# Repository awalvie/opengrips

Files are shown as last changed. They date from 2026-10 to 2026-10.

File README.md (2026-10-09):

<div align="center">
  opengrips icon
  <h1>opengrips</h1>
  <p>A lift block for finger training that you can print yourself, with grips you swap by hand. Think of a portable hangboard.</p>
  <p>
    <a href="https://awalvie.github.io/opengrips/">Configurator</a> ·
    <a href="PRINTING.md">Printing guide</a> ·
    <a href="TODO.md">To do</a> ·
    <a href="https://github.com/awalvie/opengrips/issues">Issues</a>
  </p>
</div>

opengrips is a lift block for finger training. One housing hangs off a carabiner, and the grips slide into it and click in place: edges, pockets and rollers.

You can build your own at [awalvie.github.io/opengrips](https://awalvie.github.io/opengrips/). Pick your grips, change the depth and the shape, and download the files. It all runs in your browser, and the page link keeps your kit, so you can bookmark it or share it.

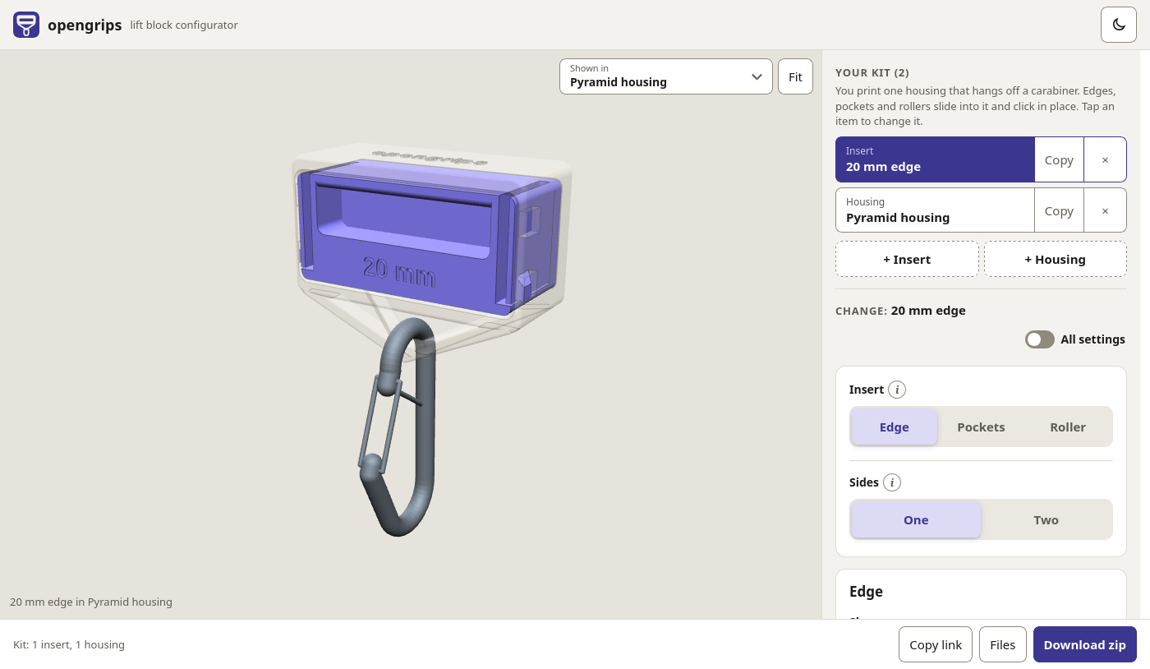
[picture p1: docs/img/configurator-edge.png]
The configurator with a 20 mm edge in the pyramid housing


This is a prototype, and I haven't load-tested it yet. Print and use it at your own risk, check it before every session, and stop using any part that cracks.

## What you can make

- Edges from 6 to 35 mm deep: flat, ergo, incut up to 20°, or slopers down to 45°.
- Two-sided inserts: any edge or pocket insert can get a second grip on its underside. Each grip is a flat or ergo edge or a row of pockets, 6 to 30 mm deep. Turn the insert over to switch.
- Pockets: mono, two-finger, three-finger, or up to three side by side.
- Rollers: unlevel or straight.
- Two anchors under the housing: a pyramid of four bars, or a keel plate with a hole.

Every anchor holds the carabiner right under the grip, so the edge should stay level when you pull. I haven't measured that yet.

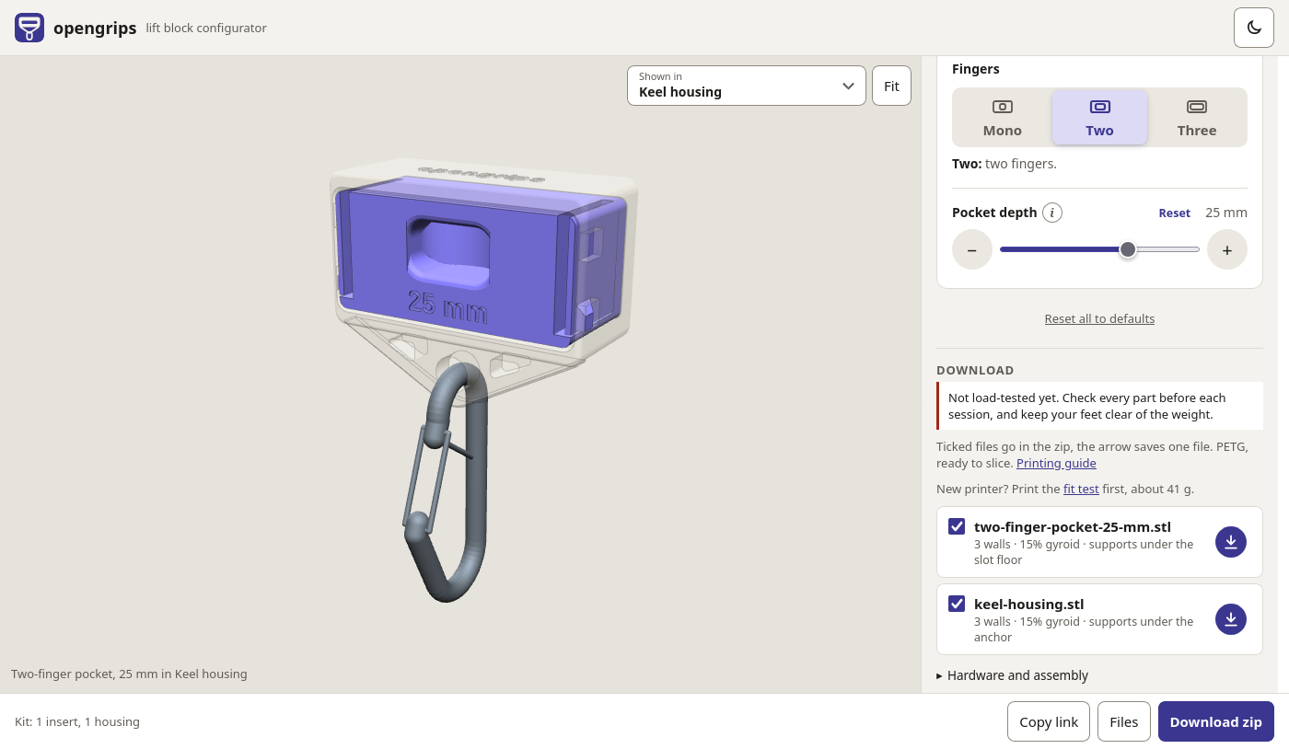
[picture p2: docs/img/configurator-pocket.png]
A two-finger pocket in the keel housing


## Printing

Print everything in PETG. The housing and two-sided inserts go on their backs, the roller frame stands upright, and the edge and pocket inserts go upside down. The files you download already sit that way. A housing and one edge insert take about 180 g of filament.

The [printing guide](PRINTING.md) has the settings, where the supports go, and how to check the fit.

## You'll also need

- A steel screwgate carabiner, and a loading pin or sling for the weights.
- For the roller, a 12 mm steel rod or dowel as the axle, or you can print one.

## Putting it together

1. For the roller, drop it between the cheeks and push the axle through.
2. Slide the insert into the housing until both side buttons click.
3. To swap it, pinch both buttons and pull the insert out by the grip. To use the other grip of a two-sided insert, turn it over and push it back in.
4. Clip the carabiner to the anchor under the housing.

## Working on it

The model is plain OpenSCAD, in `opengrips.scad` and `src/`. You can set any parameter from the command line:

```sh
openscad -D 'part="insert_edge"' -D slot_d=15 -o edge.stl opengrips.scad
```

To run the configurator locally, start `python3 web/server.py` and open http://localhost:8000. `web/catalog.py` lists what it offers.

`python3 tools/check_parts.py` renders every preset and the extremes of each setting, and checks that the parts still hold together. It needs OpenSCAD, Node.js, and Python with trimesh and manifold3d, or run `nix develop` to get them all. Add `-e native` to skip the Node.js renderer.

If you find a problem or print one, [open an issue](https://github.com/awalvie/opengrips/issues).

## License

The design is under [CERN-OHL-S-2.0](LICENSE). The configurator runs a copy of [OpenSCAD](https://openscad.org/) in the browser, which is GPL-2.0; see `web/static/vendor/openscad/`.

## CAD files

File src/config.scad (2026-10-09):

// Insert interface: every housing has this pocket, every insert fits it.
// The pocket opens to the front. Inserts slide in from the front.

pk_w = 114; pk_h = 52; pk_d = 48; r_in = 4;  // pocket envelope: room for a 28 mm roller and the fingers around it
clear = 0.3;                                 // gap between insert and pocket, per side

// Anchor plane: the anchor sits under it, so the edge stays flat under load.
// Lip + 8 mm, near where the finger pads load (a guess, to be tested). The roller axle sits on it.
grip_y = 8;

// Housing walls around the pocket. Every housing shares these, so every housing takes every insert.
floor_t = 8; side_t = 4; top_t = 8; back_t = 3;
W = pk_w + 2*side_t; H = floor_t + pk_h + top_t; D = pk_d + back_t;
ins_bot = floor_t + clear; ins_top = floor_t + pk_h - clear;   // bottom and top of every insert

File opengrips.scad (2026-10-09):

// opengrips: a 3D-printable lift block (a portable hangboard) with swappable inserts.
// Render one part: openscad -D 'part="housing"' -o housing.stl opengrips.scad
// Any parameter in src/ can be overridden the same way, for example -D slot_d=25.

part = "housing";
$fn = 48;

include <src/lib.scad>
include <src/config.scad>
include <src/latch.scad>
include <src/housing.scad>
include <src/inserts/edge.scad>
include <src/inserts/pocket.scad>
include <src/inserts/roller.scad>
include <src/inserts/flip.scad>
include <src/refs.scad>
include <src/fit_test.scad>

// for_print = true turns a printed part to the orientation in its print note and puts it on z = 0.
// The parts are modelled where they sit in the assembled block.
for_print = false;
module on_bed() {
    if (!for_print) children();
    else if (part == "housing") translate([0, 0, D]) rotate([-90, 0, 0]) children();   // back face down, pocket opening up
    else if (part == "insert_edge" || part == "insert_pocket")
        translate([0, 0, ins_top]) rotate([180, 0, 0]) children();      // top face down
    else if (part == "insert_flip") translate([0, 0, pk_d - clear]) rotate([-90, 0, 0]) children();   // on its back, front up
    else if (part == "insert_roller") translate([0, 0, -ins_bot]) children();  // floor down
    else if (part == "roller" || part == "roller_straight")
        translate([0, 0, roll_len/2]) rotate([0, 90, 0]) translate([0, -grip_y, -roll_z]) children();   // on one end
    else if (part == "axle") translate([0, -grip_y, axle_d/2 - roll_z]) children();     // lying down
    else if (part == "fit_ring" || part == "fit_frame") rotate([90, 0, 0]) children();   // front face down: the ring's flared first layer stays in its bevel, the frame's leads into the ring
    else if (part == "fit_channel") translate([0, 0, D]) rotate([-90, 0, 0]) children();          // on its back, like the housing
    else if (part == "fit_cheek") translate([0, 0, pk_d - clear]) rotate([-90, 0, 0]) children();  // on its back: the arm grows from its root
    else children();
}

on_bed() {
    if (part == "housing") housing();
    if (part == "insert_edge") insert_edge();
    if (part == "insert_pocket") insert_pocket();
    if (part == "insert_flip") insert_flip();
    if (part == "insert_roller") insert_roller();
    if (part == "roller") roller_any();
    if (part == "roller_straight") roller_straight();
    if (part == "axle") axle();
    if (part == "fit_ring") fit_ring();
    if (part == "fit_frame") fit_frame();
    if (part == "fit_channel") fit_channel();
    if (part == "fit_cheek") fit_cheek();
}
if (part == "finger") finger();
if (part == "carabiner") carabiner(seat_z());
if (part == "pin") loading_pin(seat_z());

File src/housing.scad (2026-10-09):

// Housing: a box around the pocket, with an anchor under it.

anchor = "pyramid";        // "pyramid" or "keel". Every anchor holds the carabiner on the anchor plane.

style = "truss";           // "truss": triangle windows in the back wall; "solid"
win_t = 5;                 // web between the windows

r_out = 2.5;               // round on every body edge
corner = 6;                // corner radius in the front view
bevel = 1.5;               // bevel around the pocket opening, also a lead-in for the insert

// Pyramid anchor (Lanta style): four flat bars from the bottom corners meet in one
// point under the anchor plane. Bars rise at 25 degrees.
leg_x = W/2 - 6; leg_z = 3;                  // bar roots, inside the floor
leg_yf = 5; leg_yb = D - 4.5;                // front and back bar centrelines at the root
bar_tf = 7; bar_wf = 10;                     // front bars: thickness (front view) x depth
bar_tb = 6; bar_wb = 7;                      // back bars
bar_angle = 25;
bar_r = 1.5;                                 // edge round on bars and apex node
node_len = 8;                                // apex node: hull of the last node_len mm of every bar
tri_apex = leg_z - leg_x * tan(bar_angle);   // the point
tri_rod_z = tri_apex + 12.35;                // carabiner seat: highest with the bend hooked over the node and no overlap (found by a fit search at 25 degrees)

function pyramid_legs() = [for (sx = [-1, 1], l = [[leg_yf, bar_tf, bar_wf], [leg_yb, bar_tb, bar_wb]])
    [[sx*leg_x, l[0], leg_z], l[1], l[2]]];

module anchor_pyramid() {
    p = [0, grip_y, tri_apex];
    for (l = pyramid_legs()) bar(l[0], p, l[1], l[2], bar_r);
    // the node is 2*eps fatter than the bars, so their faces never meet exactly
    hull() for (l = pyramid_legs())
        bar(p + (l[0] - p) * node_len / norm(l[0] - p), p, l[1] + 2*eps, l[2] + 2*eps, bar_r);
}

// Keel: a full-width triangle plate under the housing, with a hole through it. It carries the
// load straight out to the side walls, like the pyramid. The carabiner rests on the bottom of
// the hole, right under the anchor plane.
keel_t = 10;                                 // plate thickness (front to back)
keel_hole = 16;                              // hole diameter
keel_wall = 7;                               // material around the hole
keel_hz = -(keel_hole/2 + 6);                // hole centre height

keel_xe = W/2 - 3; keel_rb = keel_hole/2 + keel_wall;
module keel_profile() hull() {
    translate([-keel_xe, 0]) square([2*keel_xe, 3]);
    translate([0, keel_hz]) circle(r = keel_rb, $fn = 64);
}

// triangle windows, one each side, for less plastic and the look of the pyramid
module keel_windows() {
    zs = keel_hz - keel_rb;
    for (m = [0, 1]) mirror([m, 0])
        offset(r = 2) offset(delta = -2)
            polygon([[keel_rb + 4, -3], [keel_xe - 18, -3], [keel_rb + 4, zs * (1 - (keel_rb + 4) / keel_xe) + 7]]);
}

module anchor_keel() difference() {
    hull() {
        xz(grip_y - keel_t/2 + 1, keel_t - 2) keel_profile();
        xz(grip_y - keel_t/2, keel_t) offset(-1) keel_profile();
    }
    xz(grip_y - keel_t/2 - 1, keel_t + 2) keel_windows();
    translate([0, grip_y, keel_hz]) rotate([90, 0, 0]) cylinder(d = keel_hole, h = keel_t + 2, center = true, $fn = 64);
}

module anchor_any() {
    if (anchor == "pyramid") anchor_pyramid();
    if (anchor == "keel") anchor_keel();
}

// height of the carabiner rod centreline at the top of its bend
function seat_z() = anchor == "keel" ? keel_hz - keel_hole/2 + 5.5 + (16 - sqrt(16*16 - keel_t*keel_t/4))   // bend drops at the fin faces
                  : tri_rod_z;

module housing_shell() {
    minkowski() {
        xz(r_out, D - 2*r_out) translate([0, H/2]) rrect(W - 2*r_out, H - 2*r_out, corner - r_out);
        sphere(r = r_out, $fn = 24);
    }
}

module pocket_cut() {
    xz(-1, pk_d + 1) translate([0, floor_t + pk_h/2]) rrect(pk_w, pk_h, r_in);
    hull() {
        xz(-1, 1 + eps) translate([0, floor_t + pk_h/2]) rrect(pk_w + 2*bevel, pk_h + 2*bevel, r_in + bevel);
        xz(bevel, eps) translate([0, floor_t + pk_h/2]) rrect(pk_w, pk_h, r_in);
    }
}

// triangle windows through the back wall, and the name on top
module housing_style_cut() {
    zs0 = floor_t + 3; zs1 = H - top_t - 3;
    L = zs1 - zs0;
    bw = pk_w - 8;
    xz(pk_d - 1, back_t + 2) translate([-bw/2, zs0]) truss_windows(bw, L, win_t);
    translate([0, D/2, H - 0.6]) linear_extrude(1)
        text("opengrips", size = 8, spacing = 1.15, font = "Liberation Sans:style=Bold", halign = "center", valign = "center");
}

module housing() {
    difference() {
        union() {
            housing_shell();
            anchor_any();
        }
        pocket_cut();
        latch_windows();
        if (style == "truss") housing_style_cut();
    }
}

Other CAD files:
src/latch.scad
src/fit_test.scad
src/inserts/edge.scad
src/inserts/flip.scad
src/inserts/pocket.scad
src/inserts/roller.scad
src/lib.scad
src/refs.scad

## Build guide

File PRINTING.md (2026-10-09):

# Printing opengrips

These settings are where I'd start. They aren't load-tested yet, so read the note in the [README](README.md) first.

## Material

Print everything in PETG. PLA gets brittle in the cold and slowly bends when it's warm, say in a car on a sunny day.

## Settings

| Part | Walls | Infill |
| --- | --- | --- |
| Housing, edge, pocket and two-sided inserts, roller frame | 3 | 15% gyroid |
| Roller | 3 | 20% |
| Printed axle | 4 | 100% |

Use a 0.4 mm nozzle and 0.2 mm layers. These parts take your whole pull, so don't go below these settings to save time.

## Which way up

Each part has one right way up. It keeps the load running along the layers and the grip smooth. The files from the configurator already sit this way, so you only need to slice them.

| Part | On the bed | Supports |
| --- | --- | --- |
| Housing | On its back, pocket opening up | Automatic, under the anchor |
| Edge or pocket insert | Upside down, top face down | Only under the slot floor |
| Two-sided insert | On its back, front up | None |
| Roller frame | Upright, floor down | Under the two cheeks, where the latch arms are cut away |
| Roller | Standing on one end | None |
| Printed axle | Lying down | None |

| Housing | Edge insert | Pocket insert |
| --- | --- | --- |
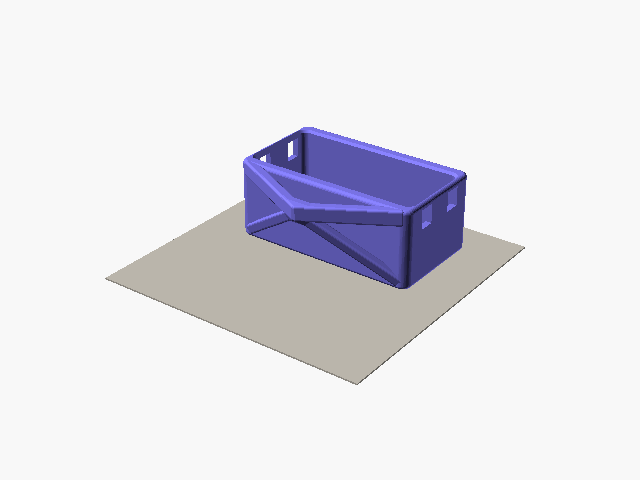
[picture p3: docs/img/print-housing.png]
Housing on the bed
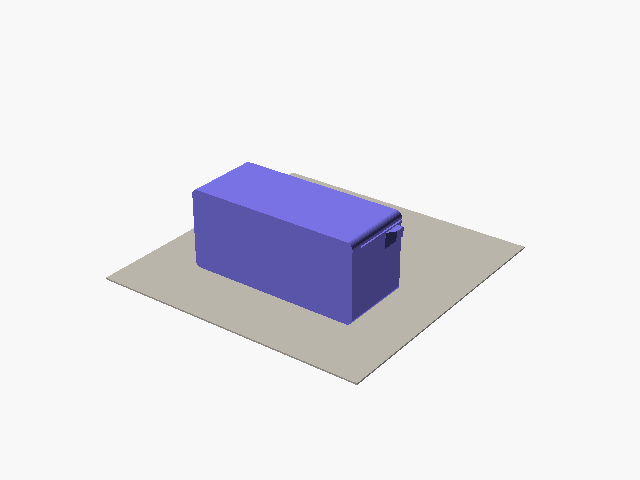
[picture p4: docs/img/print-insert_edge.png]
Edge insert on the bed
|  |  | Pocket insert on the bed |

| Roller frame | Roller | Axle |
| --- | --- | --- |
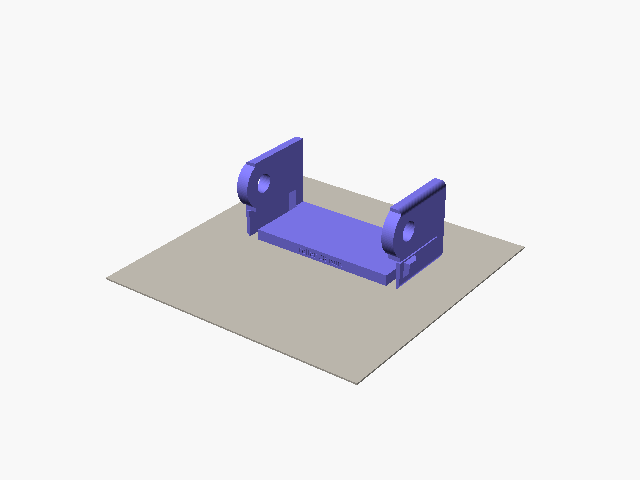
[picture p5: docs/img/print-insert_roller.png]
Roller frame on the bed
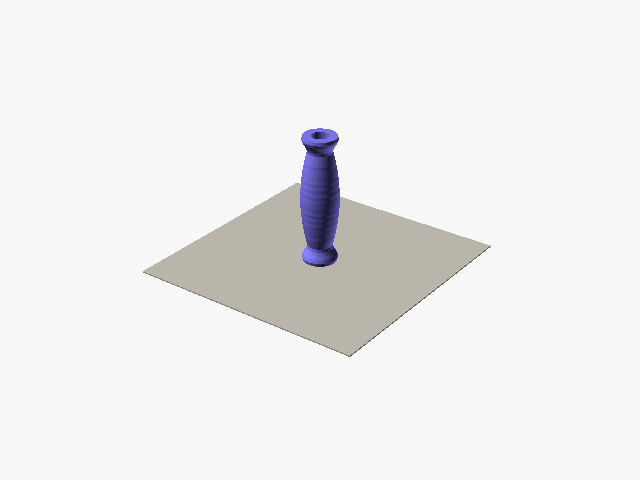
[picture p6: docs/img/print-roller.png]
Roller on the bed
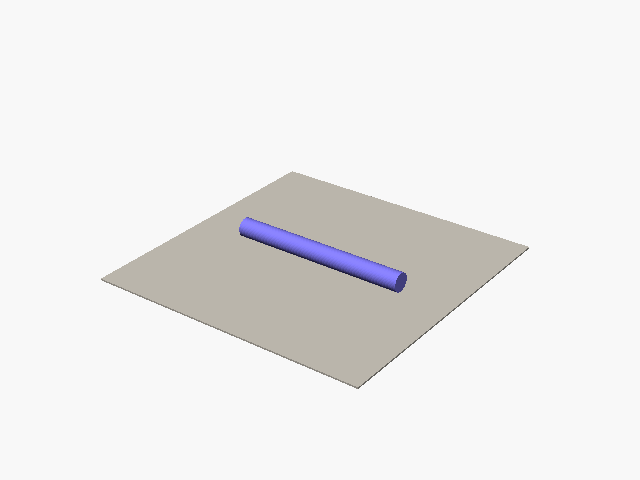
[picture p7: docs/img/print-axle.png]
Axle on the bed
|  |  |  |

| Two-sided insert |
| --- |
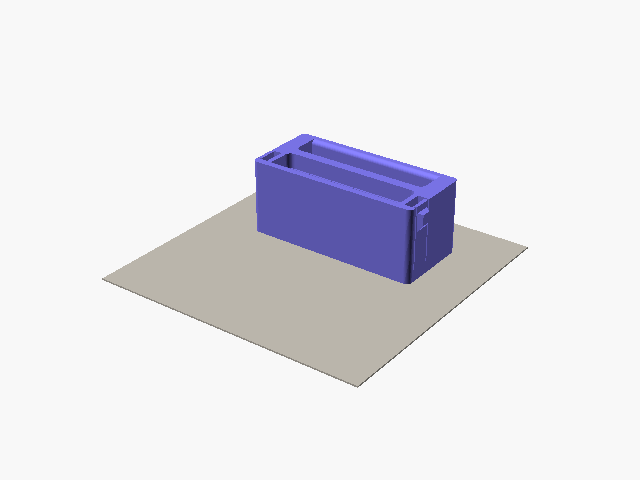
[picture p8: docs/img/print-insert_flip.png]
Two-sided insert on the bed
|  |

If you render a part yourself, add `-D for_print=true` to get it the right way up:

```sh
openscad -D 'part="housing"' -D for_print=true -o housing.stl opengrips.scad
```

## How much filament

I sliced the default parts in PrusaSlicer 2.9.6 with the settings above, PETG at 1.27 g/cm³, and no supports. Nothing has been weighed after a real print yet.

| Part | Filament |
| --- | --- |
| Housing, pyramid anchor | 93 g |
| Housing, keel anchor | 90 g |
| Edge insert, 20 mm | 87 g |
| Pocket insert, three-finger | 88 g |
| Two-sided insert, 20 and 10 mm edges | 87 g |
| Roller frame | 41 g |
| Roller, unlevel | 25 g |
| Roller, straight | 30 g |
| Printed axle | 17 g |

Automatic supports add about 18 g to the pyramid housing and about 6 g to the roller frame. A housing and one edge insert come to about 180 g, so a 1 kg spool gets you a housing and about ten inserts.

## The fit test

On a new printer, print the fit test before the kit. In the configurator, click "fit test" under Download. You get one zip with four small parts, already the right way up. Use the housing settings above.

- The ring is a thin slice of the housing pocket, and the frame is a thin slice of an insert. Push the frame into the ring. It must slide in without force.
- The latch channel is a short piece of housing wall with the real window, and the latch cheek is one side of an insert with the real latch arm. Slide the cheek into the channel until the button clicks into the window. Then press the button in and pull the cheek out by its tab.

If a pair sticks, follow step 3 below, then print the fit test again.

## Checking the fit

1. Slide the insert into the housing. Both side buttons should click into their windows.
2. Pinch both buttons and pull the insert out by the grip. It should come out without a fight.
3. If it sticks, look at the face that was on the bed. A flared first layer, the "elephant's foot", is the usual cause. Trim or sand that edge, or turn on elephant-foot compensation in your slicer.

## Before your first session

- Pull out all the supports, and make sure none are left in the slot or the latch windows.
- Look for split layers at the anchor, around the latch arms and at the grip. Don't use a cracked part.
- Hang the block from the carabiner and load it slowly by hand before you pull hard.

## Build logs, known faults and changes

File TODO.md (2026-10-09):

# To do

- Photo of a printed kit and a short video of a pull, for the README.
- Load-test each anchor to failure. Publish the load, how it failed, and the material, orientation, walls and infill.
- Measure edge pitch under load, for each anchor and for shallow, deep and ergo edges.
- Real filament grams and print times from a printed kit, to check the slicer numbers in PRINTING.md.
- Check the 0.3 mm insert clearance on a few printers with the fit test.

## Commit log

2026-10-08 feat: add the OpenSCAD model: housing, anchors and inserts
    [config.scad, edge.scad, housing.scad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]
2026-10-08 test: add check_parts.py to catch broken prints
2026-10-08 fix(catalog): call it pocket depth on pocket inserts
2026-10-08 refactor(ui): drop the duplicate Simple/Advanced switch
2026-10-08 test(check): probe the slot off-centre too
    The core cavities are triangles, so a centreline probe can sit on a web and miss a break into the core beside it.
2026-10-08 fix(pocket): keep the mouth round under the rail
    The mouth round runs its full radius up the face, but the ceiling only reserved the lip run-up, so big rounds on slopers cut through the top rail. Where the slot cannot spare the room, the round shrinks instead of the slot.
    [edge.scad, pocket.scad]
2026-10-08 test(check): check the rail over the slot at the face
2026-10-08 feat(housing): centre the carabiner on the bolt
    Between the outer legs the carabiner could slide 20 mm off-centre and roll the block. The inner legs also shorten the bolt's bending span.
    [housing.scad]
2026-10-08 fix(catalog): print the housing on its back
    On its side the anchor bars, top wall and floor load across the layer lines; on its back they all lie within layers and need less support.
2026-10-08 fix(catalog): stop calling every bolt M10
    The legs span 70 mm outside to outside; 90 mm leaves room for an M12 nut and washers.
2026-10-08 fix(ui): ask for a 90 mm bolt in the hardware list
2026-10-08 fix(ui): frame the model below the overlay on phones
2026-10-08 feat(scad): add a print switch that puts each part on the bed
    [opengrips.scad]
2026-10-08 feat(refs): make the carabiner a wire gate like a real one
    [refs.scad]
2026-10-08 docs: add a printing guide
2026-10-08 feat(ui): download parts turned for printing
2026-10-08 fix(catalog): stop promising the edge stays flat
    Nothing has measured edge pitch under load yet.
2026-10-08 docs: rewrite the printing guide in plain words
2026-10-08 feat: remove the bolt anchor
    [housing.scad, opengrips.scad]
2026-10-08 feat(ui): cut the download list down to one line per file
2026-10-08 feat(ui): keep the shape buttons when all settings show
2026-10-08 feat: drop the hollow insert core
    [edge.scad, pocket.scad]
2026-10-08 docs: print with 3 walls and 15% infill
2026-10-09 refactor: let one part have two different edges
    Needed for the flip insert. No shapes change.
    [edge.scad, refs.scad]
2026-10-09 feat: add a second pair of latch windows up top
    So a flipped insert still clicks in.
    [latch.scad]
2026-10-09 feat: add the flip insert, two edges in one
    It's not in the configurator yet, that comes next.
    [flip.scad, latch.scad, opengrips.scad]
2026-10-09 feat(ui): let people pick the flip insert
2026-10-09 docs: explain the flip insert
2026-10-09 docs: stop calling it a no-hang block
    [opengrips.scad]
2026-10-09 feat: add a fit test you can print first
    [fit_test.scad, opengrips.scad]
2026-10-09 fix: stop the latch arm leaving junk in downloaded files
    The arm sat exactly on the side of the insert, and the browser's OpenSCAD left
    paper-thin bits there. Every insert you downloaded had mesh errors.
    [latch.scad]
2026-10-09 fix: build the pocket in one piece
    The old stacked shapes left the same junk at steep angles. The pocket looks
    the same.
    [edge.scad]
2026-10-09 fix: show an error when the 3D renderer can't start
    Before, one failed start left every render after it stuck on "Rendering…".
2026-10-09 refactor: use one overlap value across the CAD code
    No shapes change.
    [edge.scad, fit_test.scad, housing.scad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]
2026-10-09 test: stop the flip check assuming an 8 mm floor
2026-10-09 refactor: let the pocket cut take its sizes
    [edge.scad]
2026-10-09 feat: put a pocket on either side of the flip insert
    [flip.scad]
2026-10-09 test: check pockets in the flip insert
2026-10-09 docs: say the flip insert takes pockets too
2026-10-09 fix: let Undo go back past several insert changes
2026-10-09 fix: make the fit test link a real button
2026-10-09 feat(ui): shorten the insert type buttons
2026-10-09 fix: keep every setting inside its own insert's limits
    A full row of pockets now makes the wall thinner once the pockets reach 18 mm, instead of going under the minimum and breaking the link.
    Claude-Session: https://claude.ai/code/session_01YRUYy73DyG7ykzXKN62jKi
2026-10-09 feat: give two-sided grips the full edge and pocket settings
    No angle on either grip: at 0° each half has 16.5 mm of finger room, and ±10° leaves 11 mm.
    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
    [flip.scad]
2026-10-09 feat(ui): hide help text behind an "i" button
    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
2026-10-09 docs: call flip inserts two-sided
    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
2026-10-09 docs: refresh the print pictures of the housing, edge and pocket
    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
2026-10-09 chore: drop model code that nothing uses
    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
    [edge.scad, housing.scad, opengrips.scad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]
2026-10-09 refactor: name the insert's top and bottom once
    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
    [config.scad, edge.scad, latch.scad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]
2026-10-09 refactor: work out the pocket row width in one place
    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
    [flip.scad, lib.scad, pocket.scad]
2026-10-09 fix: keep a small roller frame in one piece
    Below a 28 mm roller, the cheek top met the clip exactly, and the browser renderer left zero-area slivers. The native renderer did not.
    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
    [roller.scad]
2026-10-09 test: render the housing and roller settings at their limits
    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
2026-10-09 chore: fix comments that no longer match the code
    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
    [edge.scad, pocket.scad]
2026-10-09 docs: say the roller frame prints upright
    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
2026-10-09 docs: add the fit test to the printing guide
    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
